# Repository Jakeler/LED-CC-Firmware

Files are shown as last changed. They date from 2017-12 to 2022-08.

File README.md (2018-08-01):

# Constant current LED Driver


Microcontroller based constant current driver. Based around a LM2596S drop down regulator (because these complete modules are cheaper than buying the components) and an Arduino Pro Mini.

The repo contains a PlatformIO project to compile the Arduino firmware. In the schematic/ subdirectory is the KiCAD project with the PCB layout, footprints, etc.

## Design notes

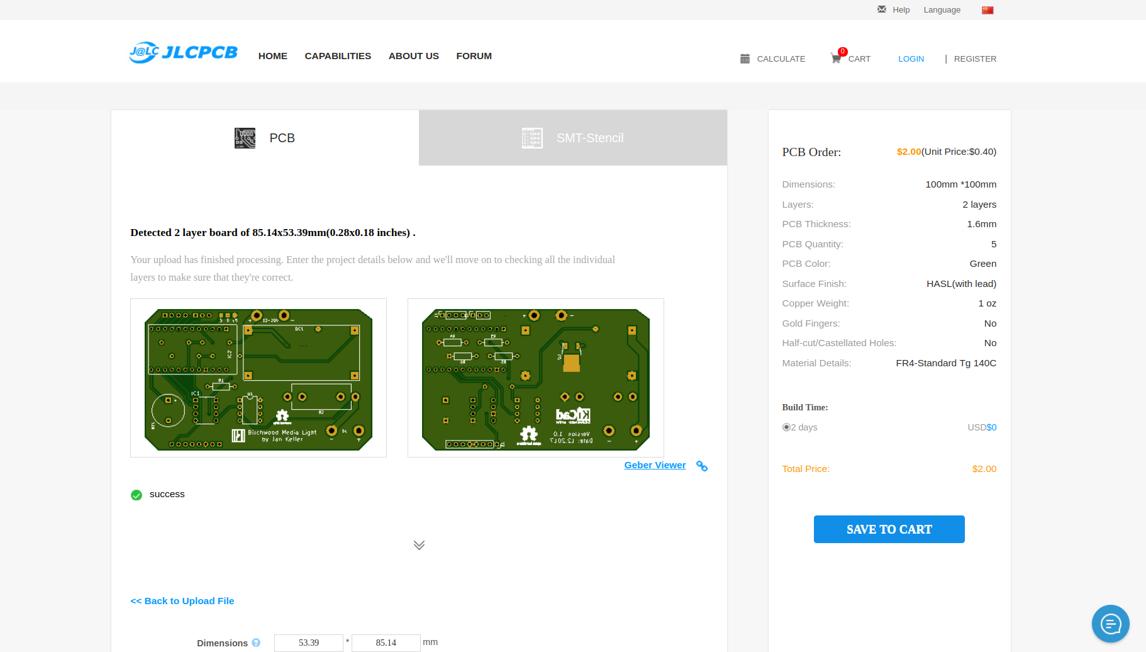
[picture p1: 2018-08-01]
schematic/Screenshot_20171218_221445.png

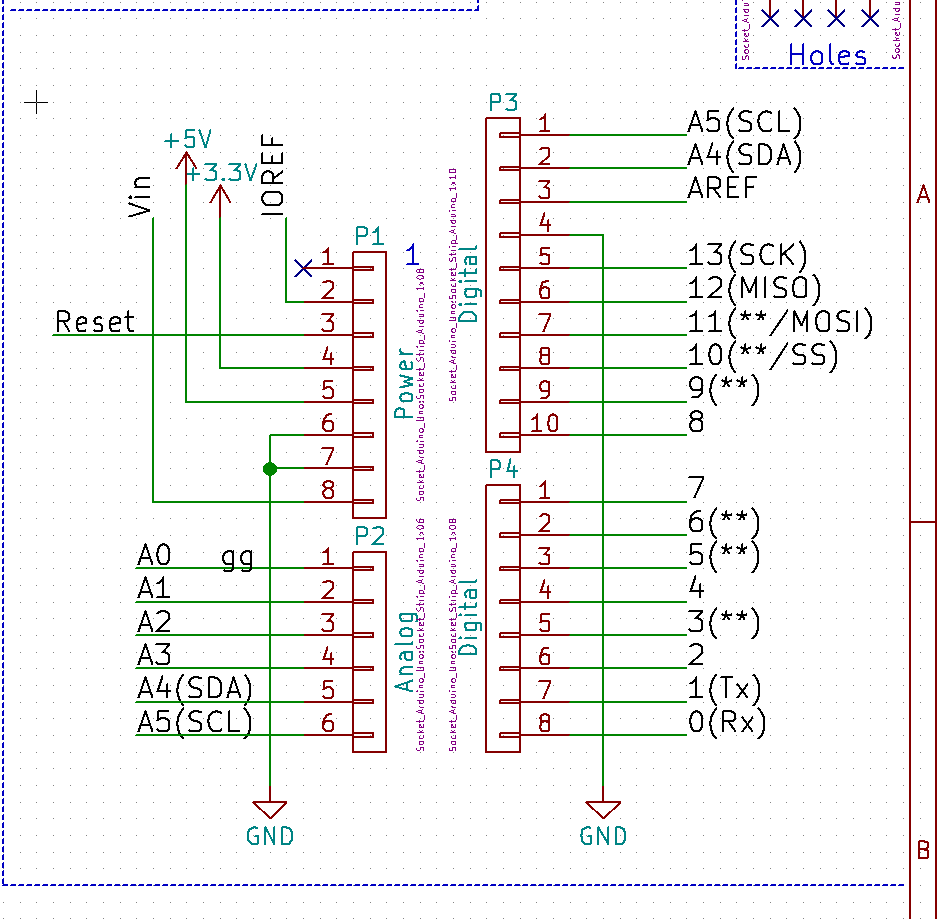
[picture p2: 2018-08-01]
schematic/Screenshot_20171111_214208.png

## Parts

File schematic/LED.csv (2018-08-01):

ID | Bezeichner | Gehäuse | Stückzahl | Bezeichnung | Anbieter und Ref.
1 | R2 | R_Axial_Shunt_L22.2mm_W9.5mm_PS14.30mm_P25.40mm | 1 | 0.39
2 | BT1 | WireConnection_2.00mmDrill | 1 | 3-4S LiPo
3 | BZ1 | Buzzer_12x9.5RM7.6 | 1 | Buzzer
4 | D1 | WireConnection_2.00mmDrill | 1 | LED
5 | DC1 | ChinaLM2596S-Module | 1 | DC-DC
6 | IC1 | DIP254P762X533-8 | 1 | X9C103P
7 | J1 | Socket_Strip_Straight_1x04_Pitch2.54mm | 1 | Conn_01x04
8 | J2 | Socket_Strip_Straight_1x03_Pitch2.54mm | 1 | Conn_01x03
9 | J3 | Socket_Strip_Straight_1x08_Pitch2.54mm | 1 | Conn_01x06
10 | R1 | R_Axial_DIN0207_L6.3mm_D2.5mm_P10.16mm_Horizontal | 1 | 20K
11 | R3,R5 | R_Axial_DIN0207_L6.3mm_D2.5mm_P10.16mm_Horizontal | 2 | 15K
12 | R4,R6 | R_Axial_DIN0207_L6.3mm_D2.5mm_P10.16mm_Horizontal | 2 | 4.7K
13 | U1 | DIP-8_W7.62mm | 1 | LM358
14 | U2 | TO-252-2 | 1 | MC78M05_TO252
15 | IC2 | ProMini | 1 | Pro Mini
16 | S,G,+5 | Measurement_Point_Square-SMD-Pad_Small | 3

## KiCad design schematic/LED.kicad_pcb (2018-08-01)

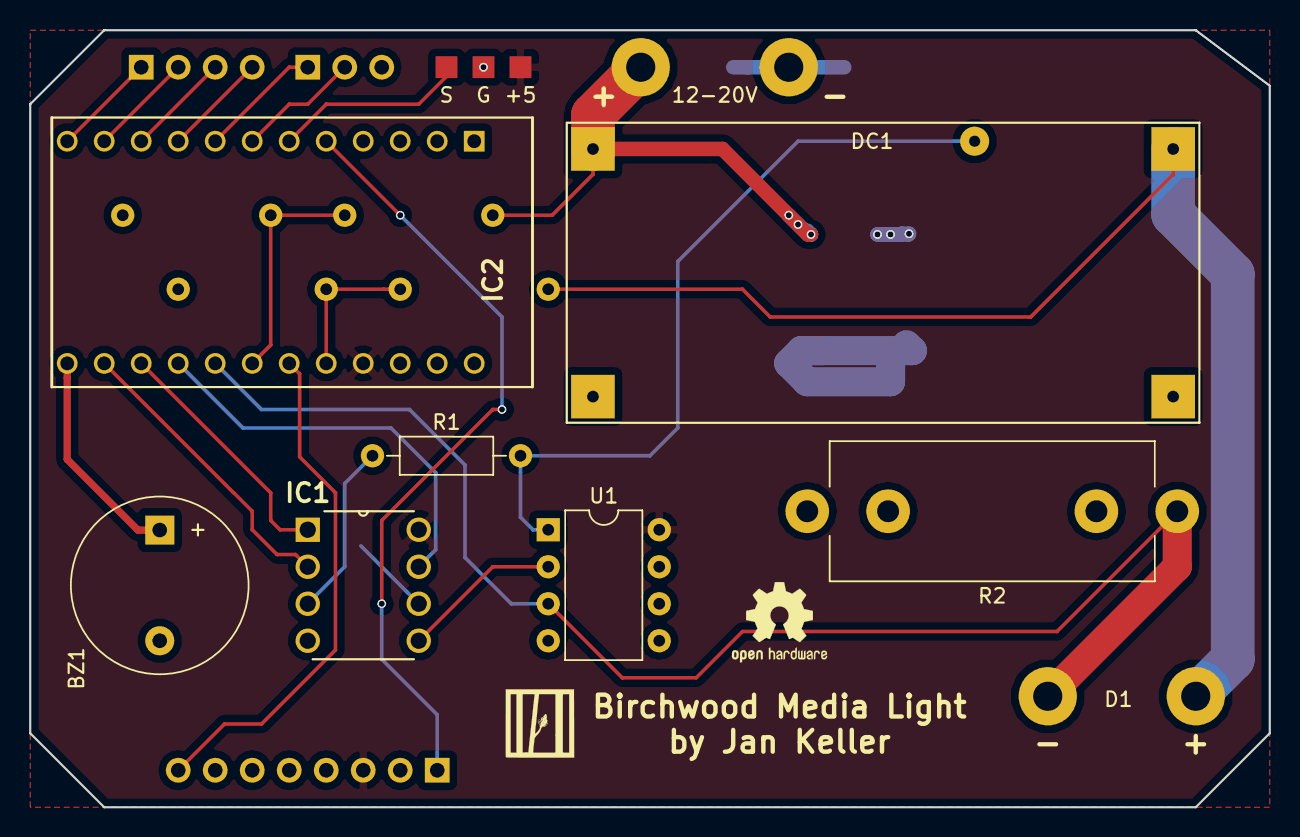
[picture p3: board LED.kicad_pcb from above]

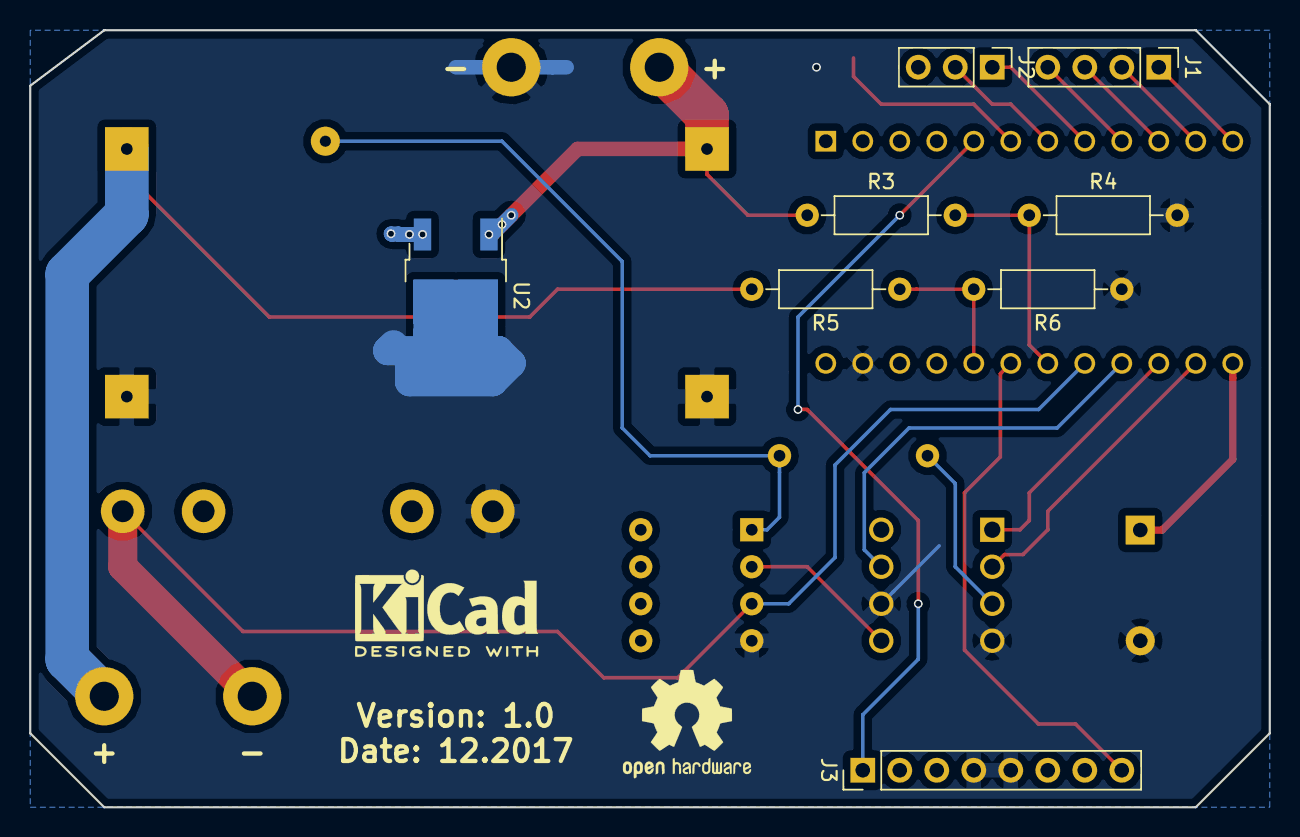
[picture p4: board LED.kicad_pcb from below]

Board: 2 copper layers, 85.1 x 53.3 mm, 20 parts (8 on the bottom side), 23 nets.

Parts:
12-20V: 3-4S LiPo; WireConnection_2.00mmDrill
+5: Measurement_Point_Square-SMD-Pad_Small
BZ1: Buzzer; Buzzer_12x9.5RM7.6
D1: LED; WireConnection_2.00mmDrill
DC1: DC-DC; ChinaLM2596S-Module
G: Measurement_Point_Square-SMD-Pad_Small
IC1: X9C103P; DIP254P762X533-8
IC2: Pro Mini; ProMini
J1: Conn_01x04; Socket_Strip_Straight_1x04_Pitch2.54mm
J2: Conn_01x03; Socket_Strip_Straight_1x03_Pitch2.54mm
J3: Conn_01x06; Socket_Strip_Straight_1x08_Pitch2.54mm
R1: 20K; R_Axial_DIN0207_L6.3mm_D2.5mm_P10.16mm_Horizontal
R2: 0.39; R_Axial_Shunt_L22.2mm_W9.5mm_PS14.30mm_P25.40mm
R3, R5: 15K; R_Axial_DIN0207_L6.3mm_D2.5mm_P10.16mm_Horizontal
R4, R6: 4.7K; R_Axial_DIN0207_L6.3mm_D2.5mm_P10.16mm_Horizontal
S: Measurement_Point_Square-SMD-Pad_Small
U1: LM358; DIP-8_W7.62mm
U2: MC78M05_TO252; TO-252-2

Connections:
+5V: +5.1, IC1.8, IC2.21, J3.3, U1.8, U2.3
+BATT: 12-20V.1, DC1.1, R3.1, U2.1
GND: 12-20V.2, BZ1.2, DC1.2, DC1.4, G.1, IC1.4, IC1.6, IC2.23, J3.4, J3.5, R2.4, R4.2, R6.1, U1.4, U2.2
unnamed: BZ1.1, IC2.13
unnamed: D1.1, IC2.17, R2.1, U1.3
unnamed: D1.2, DC1.5, R5.2
unnamed: DC1.3, R1.2, U1.1
unnamed: IC1.1, IC2.15
unnamed: IC1.2, IC2.14
unnamed: IC1.3, R1.1
unnamed: IC1.5, U1.2
unnamed: IC1.7, IC2.16
unnamed: IC2.5, J3.1
unnamed: IC2.6, S.1
unnamed: IC2.7, J2.2
unnamed: IC2.8, J2.1
unnamed: IC2.9, J1.4
unnamed: IC2.10, J1.3
unnamed: IC2.11, J1.2
unnamed: IC2.12, J1.1
unnamed: IC2.18, R3.2, R4.1
unnamed: IC2.19, J3.8
VS: IC2.20, R5.1, R6.2

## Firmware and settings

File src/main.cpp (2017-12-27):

#include <Arduino.h>
#include <Wire.h>
#include <LiquidCrystal.h>

#define VIN A1
#define VOUT A3
#define AOUT A0
#define AOUT_MAX 12.8205
#define BTN A2
#define VIN_MAX 20.957
#define LI_cell 3.0
#define LI_minV 3.5
#define INC_PIN 12
#define UP_PIN 11
#define CS_PIN 13
#define BEEP_PIN 10
#define MAX_STANDBY 60

int pot_pos = 100, power = 10, standby_count = 0;

LiquidCrystal lcd(5, 4, 9, 8, 7, 6);

uint8_t light[8]  = {B0,B00011,B00111,B01111,B11111,B01111,B00111,B00011};
uint8_t shine[8] = {0x0,0x0,0x1F,0x0,0x1F,0x0,0x1F,0x0};

uint8_t start[8]  = {B1,B1,B1,B1,B1,B1,B1,B1};
uint8_t end[8]  = {B10000,B10000,B10000,B11000,B11000,B10000,B10000,B10000};
uint8_t leer_mid[8]  = {B11111,B0,B0,B0,B0,B0,B0,B11111};
uint8_t full_mid[8] = {0x1F,0x0,0x1F,0x1F,0x1F,0x1F,0x0,0x1F};

int buttons[5] = {10, 150, 300, 500, 700};

void beep(int, int);
void setPot(int);
bool selfTest();

void initLCD() {
  lcd.begin(16,2);
  lcd.createChar(3, start);
  lcd.createChar(0, leer_mid);
  lcd.createChar(1, full_mid);
  lcd.createChar(4, end);
  lcd.createChar(5, light);
  lcd.createChar(6, shine);

  if (selfTest()) {
    lcd.setCursor(0, 1);
    lcd.print("                ");
    lcd.setCursor(0, 1);
    lcd.print("PASSED!");
  } else {
    setPot(-100);
    lcd.print("FAIL!");
    while (true);
  }
}

bool selfTest() {
  lcd.home();
  lcd.print("# Self Test: 0%");
  lcd.setCursor(0, 1);
  setPot(0-pot_pos);
  for (uint8_t i = 0; i < 3; i++) {
    delay(200);
    float outV = analogRead(VOUT)/1023.0*VIN_MAX;
    float outA = analogRead(AOUT)/1023.0*AOUT_MAX;
    lcd.print(String(outV, 1)+" ");
    if (outV < 3.0 || outV > 7.0 || outA > 0.01) return false;
  }
  lcd.print("OK!");
  delay(200);

  lcd.setCursor(13, 0);
  lcd.print("50%");
  lcd.setCursor(0, 1);
  lcd.print("                ");
  lcd.setCursor(0, 1);
  setPot(50-pot_pos);
  for (uint8_t i = 0; i < 3; i++) {
    delay(200);
    float outV = analogRead(VOUT)/1023.0*VIN_MAX;
    float outA = analogRead(AOUT)/1023.0*AOUT_MAX;
    lcd.print(String(outV, 1)+" ");
    if (outA < 0.35 || outA > 0.55 || outV < 9.0 || outV > 11.0) return false;
  }
  lcd.print("OK!");
  delay(200);

  return true;
}

void setPot(int change) {
  digitalWrite(INC_PIN, 1);
  digitalWrite(CS_PIN, 0);
  delay(1);

  if (change > 0) {
    digitalWrite(UP_PIN, 1);
  } else {
    digitalWrite(UP_PIN, 0);
  }

  int change_abs = abs(change);
  digitalWrite(INC_PIN, 1);
  for (int i = 0; i < change_abs; i++) {
    digitalWrite(INC_PIN, 0);
    delay(1);
    digitalWrite(INC_PIN, 1);
    delay(1);
  }
  pot_pos += change;

  digitalWrite(CS_PIN, 1);
}

void initPot() {
  pinMode(CS_PIN, OUTPUT);
  digitalWrite(CS_PIN, 1);
  pinMode(INC_PIN, OUTPUT);
  digitalWrite(INC_PIN, 1);
  pinMode(UP_PIN, OUTPUT);
  setPot(-100);
}

void readButtons() {
  uint16_t value = analogRead(BTN);
  if (value < 10) {
    // RIGHT
    power += 10;
    beep(50,1);

  } else if (value < 150) {
    // UP
    power++;
    beep(20,1);

  } else if (value < 300) {
    // DOWN
    power--;
    beep(20,1);

  } else if (value < 500) {
    // LEFT
    power -= 10;
    beep(50,1);

  } else if (value < 700) {
    // SELECT
    if (power == 0) {
      power = 100;
      beep(100,1);
    } else {
      power = 0;
      beep(100,1);
    }
  } else {
    // no Button
  }
  if (power > 100) {
    power = 100;
    beep(100,1);
  } else if (power < 0) {
    power = 0;
    beep(100,1);
  }
}

void checkStandby() {
  if (power == 0) {
    standby_count++;
  } else {
    standby_count = 0;
  }
  if (standby_count >= MAX_STANDBY) {
    beep(100, 3);
    standby_count -= 10;
  }
}

void beep(int duration, int count) {
  for (int i = 0; i < count; i++) {
    digitalWrite(BEEP_PIN, 1);
    delay(duration);
    digitalWrite(BEEP_PIN, 0);
    delay(duration);
  }
}

void setup() {

  digitalWrite(BEEP_PIN, 0);
  pinMode(BEEP_PIN, OUTPUT);
  pinMode(VIN, INPUT);
  pinMode(VOUT, INPUT);
  pinMode(AOUT, INPUT);
  pinMode(BTN, INPUT);

  initPot();
  initLCD();
  beep(200, 2);
}

void updateLcd(float batV, float charge, float watt) {
  lcd.clear();
  lcd.print(String(batV, 1) + "V");
  lcd.setCursor(5, 0);
  lcd.write(3);
  for (float i = 0.125; i < 1.1; i+= 0.125) {
    if(charge >= i) {
      lcd.write(1);
    } else {
      lcd.write(byte(0));
    }
  }
  lcd.write(4);

  lcd.setCursor(0, 1);
  lcd.write(5);
  for (float i = 0.0; i < 1.1; i+= 0.25) {
    if(pot_pos/100.0 >= i) {
      lcd.write(6);
    } else {
      lcd.print(" ");
    }
  }
  lcd.print(pot_pos);
  lcd.print("% " +String(watt, 1) + "W");
}

void loop() {
    readButtons();
    float batV = analogRead(VIN)/1023.0*VIN_MAX;
    float outV = analogRead(VOUT)/1023.0*VIN_MAX;
    float outA = analogRead(AOUT)/1023.0*AOUT_MAX;
    float cellV = batV/LI_cell;
    float charge = (cellV-LI_minV)/(4.2-LI_minV);
    if (charge <= 0.0) {
      power = 0;
      setPot(power-pot_pos);
      beep(500, 3);
    }
    setPot(power-pot_pos);

    checkStandby();

    updateLcd(batV, charge, outA*outV);

    //lcd.print(String(pot*100, 0) + "% " + String(pot*10, 1) + "W");
    delay(500);
}

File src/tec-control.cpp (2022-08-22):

#include <Arduino.h>
#include <LiquidCrystal.h>
#include <OneWire.h>
#include <DallasTemperature.h>
#include <QuickPID.h>
#include "Sensors.h"
#include "ConstantCurrent.h"
#include "ButtonsBeep.h"

#define DEBUG_PID

LiquidCrystal lcd(5, 4, 9, 8, 7, 6);
OneWire oneWire(3);
DallasTemperature sensors(&oneWire);

ConstantCurrent cc(INC_PIN, UP_PIN, CS_PIN);
PowerSensor ps(VIN_PIN, VOUT_PIN, AOUT_PIN);
Beeper beeper(BEEP_PIN);

float setpoint = 15.0, input, output;
float Kp = 10, Ki = 4, Kd = 5;
QuickPID myPID(&input, &output, &setpoint, Kp, Ki, Kd, QuickPID::Action::reverse);

class Buttons: public ButtonInterface {
  using ButtonInterface::ButtonInterface;

  void handleUP() {
    cc.changeTargetPercent(+2);
    lcd.print("UP");
  };
  void handleDOWN() {
    cc.changeTargetPercent(-2);
    lcd.print("DOWN");
  };
  void handleRIGHT() {
    setpoint += 2;
    lcd.print("RIGHT");
  };
  void handleLEFT() {
    setpoint -= 2;
    lcd.print("LEFT");
  };
  void handleSELECT() {
    cc.setOuputState(!cc.isOutputEnabled);
    lcd.print("SLT");
  };
};
Buttons btns(BTN_PIN);

void updateLcd() {
  ps.readCurrentData();
  
  bool regulating = true;
  float temps[] = {sensors.getTempCByIndex(0), sensors.getTempCByIndex(1), setpoint};
  input = temps[1];
  lcd.clear();
  auto onChar = regulating? '>' : ' ';
  lcd.print(String(temps[0], 1) + "\xDF" + onChar + String(temps[1], 1) + "/" + String(temps[2], 1) + "\xDF");

  lcd.setCursor(0, 1);
  auto stateChar = cc.isOutputEnabled? '=' : ' ';
  lcd.print(String(ps.outputAmps, 2) + "A" + stateChar + String(cc.targetPercent) + "%");
  lcd.print(" " + String(ps.outputWatts, 2) + "W");
}

void setup() {
  lcd.begin(16, 2);
  cc.init();
  beeper.init();

  sensors.begin();
  sensors.setResolution(11);

  myPID.SetOutputLimits(0, 64);
  myPID.SetMode(QuickPID::Control::automatic);

  #ifdef DEBUG_PID
    Serial.begin(250000);
  #endif
}

void loop() {
  btns.chooseButton();
  sensors.requestTemperatures(); // takes 375 ms at 11 bit
  // delay(200);
  updateLcd();
  myPID.Compute();
  cc.setTargetPercent(output);

  #ifdef DEBUG_PID
    Serial.println("in: " + String(input) + "/" + String(setpoint));
    Serial.println("out: " + String(output) + " = " + String(sqrt(output*64)));
    Serial.println("P: " + String(myPID.GetPterm()));
    Serial.println("I: " + String(myPID.GetIterm()));
    Serial.println("D: " + String(myPID.GetDterm()));
  #endif
}

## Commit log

2017-12-27 Import Prototype
2017-12-27 Add output voltage/current mesurment
2017-12-27 Add self test at startup and power display
2018-08-01 Add KiCAD schematics
    [LED.csv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]
2018-08-01 Mention schematics in Readme
2022-08-07 Add more general constant current firmware
2022-08-07 Add enable/disable button function
2022-08-10 Use source filter for different variants also more stuff in common [env]
2022-08-13 Build libs for current and sensors
2022-08-13 Move target und powered global var into class
2022-08-14 Create button/beeper class lib
2022-08-15 Pin definitions as class member var
2022-08-15 Create PowerSensor class for volt/amp/watt reading
